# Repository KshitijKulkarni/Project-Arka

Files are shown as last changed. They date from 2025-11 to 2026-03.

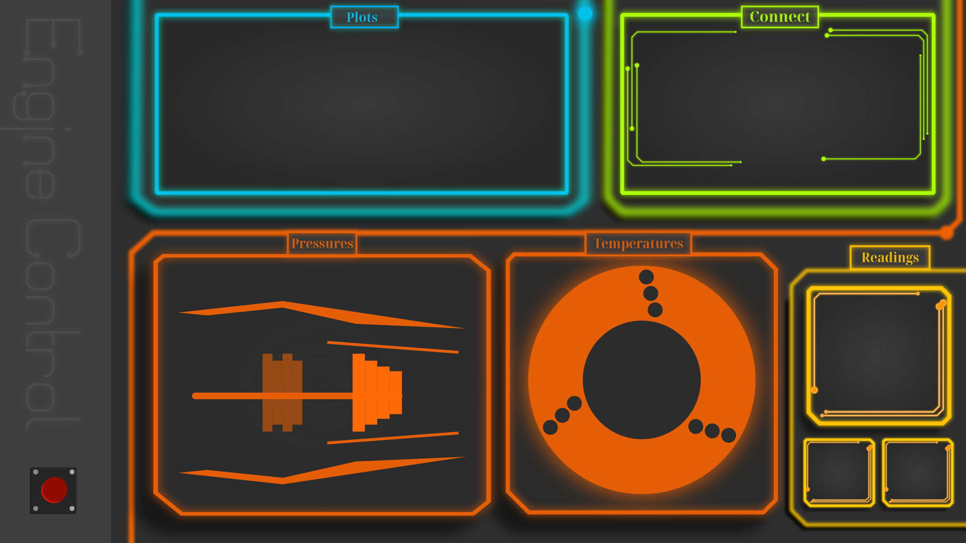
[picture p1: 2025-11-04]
Ground Control Code/Flutter/flutterprojs/assets/BGNew.png

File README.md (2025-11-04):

# Project-Arka
The project code base is split on two folders
1. Microcontroller Code - All code that will be run/tested on microcontrollers (Teensy 4.1, Arduino UNO etc)
2. Ground Control Code - All code that will be run on a system external to the engine (includes code for the GUI)

## Microcontroller Code
The files in this folder are sorted as follows
```
Microcontroller Code
├── moduleTestCodes
└── <microcontrollerBoardname>
    ├── <microcontrollerBoardname>.ino
    └── src
        ├── HelperModule1
        │   ├── HelperModule1.h
        │   └── HelperModule1.cpp
        ├── HelperModule2
        │   ├── HelperModule2.h
        │   └── HelperModule2.cpp
        └── HelperModule3
            ├── HelperModule3.h
            └── HelperModule3.cpp
```

The moduleTestCodes directory contains code for testing individual sensor/motor modules, which are not directly suitable for reuse in the final project.

## Ground Control Code

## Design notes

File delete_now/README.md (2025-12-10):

# delete_now

A new Flutter project.

## Getting Started

This project is a starting point for a Flutter application.

A few resources to get you started if this is your first Flutter project:

- [Lab: Write your first Flutter app](https://docs.flutter.dev/get-started/codelab)
- [Cookbook: Useful Flutter samples](https://docs.flutter.dev/cookbook)

For help getting started with Flutter development, view the
[online documentation](https://docs.flutter.dev/), which offers tutorials,
samples, guidance on mobile development, and a full API reference.

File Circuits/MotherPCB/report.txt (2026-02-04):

Plotted to 'C:\Users\akkia\Downloads\Arka_PCB\Project-Arka\Circuits\MotherPCB\MotherPCB-Front.gbr'.
Plotted to 'C:\Users\akkia\Downloads\Arka_PCB\Project-Arka\Circuits\MotherPCB\MotherPCB-Back.gbr'.
Plotted to 'C:\Users\akkia\Downloads\Arka_PCB\Project-Arka\Circuits\MotherPCB\MotherPCB-F_Paste.gbr'.
Plotted to 'C:\Users\akkia\Downloads\Arka_PCB\Project-Arka\Circuits\MotherPCB\MotherPCB-B_Paste.gbr'.
Plotted to 'C:\Users\akkia\Downloads\Arka_PCB\Project-Arka\Circuits\MotherPCB\MotherPCB-F_Silkscreen.gbr'.
Plotted to 'C:\Users\akkia\Downloads\Arka_PCB\Project-Arka\Circuits\MotherPCB\MotherPCB-B_Silkscreen.gbr'.
Plotted to 'C:\Users\akkia\Downloads\Arka_PCB\Project-Arka\Circuits\MotherPCB\MotherPCB-F_Mask.gbr'.
Plotted to 'C:\Users\akkia\Downloads\Arka_PCB\Project-Arka\Circuits\MotherPCB\MotherPCB-B_Mask.gbr'.
Plotted to 'C:\Users\akkia\Downloads\Arka_PCB\Project-Arka\Circuits\MotherPCB\MotherPCB-Edge_Cuts.gbr'.
Created Gerber job file 'C:\Users\akkia\Downloads\Arka_PCB\Project-Arka\Circuits\MotherPCB\MotherPCB-job.gbrjob'.
Info: Done.
Info: Done.

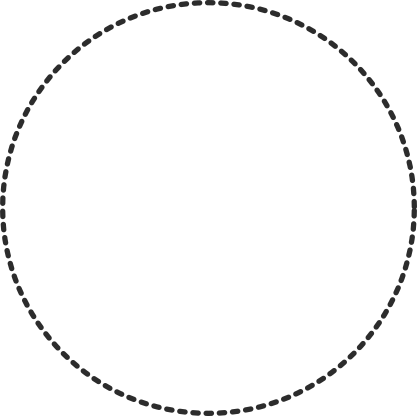
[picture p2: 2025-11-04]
Ground Control Code/Flutter/flutterprojs/assets/L.png

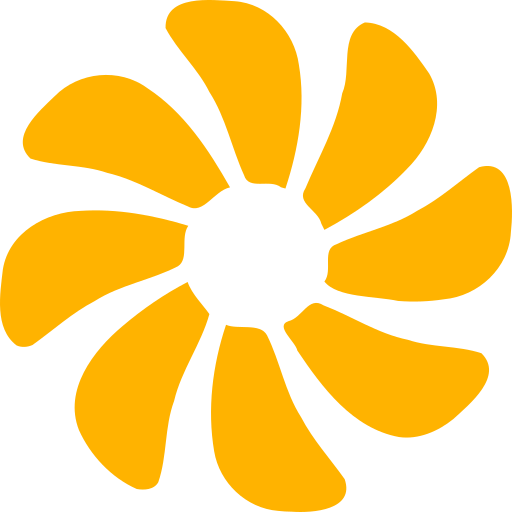
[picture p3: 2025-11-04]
Ground Control Code/Control Panel GUI/QtGUI/UntitledProject/UntitledProjectContent/images/Fan Blades.png

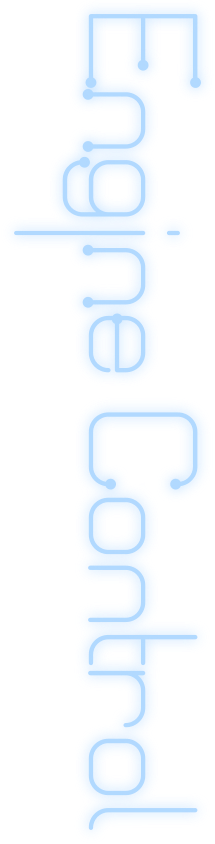
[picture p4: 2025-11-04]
Ground Control Code/Control Panel GUI/QtGUI/UntitledProject/UntitledProjectContent/images/Signboard.png

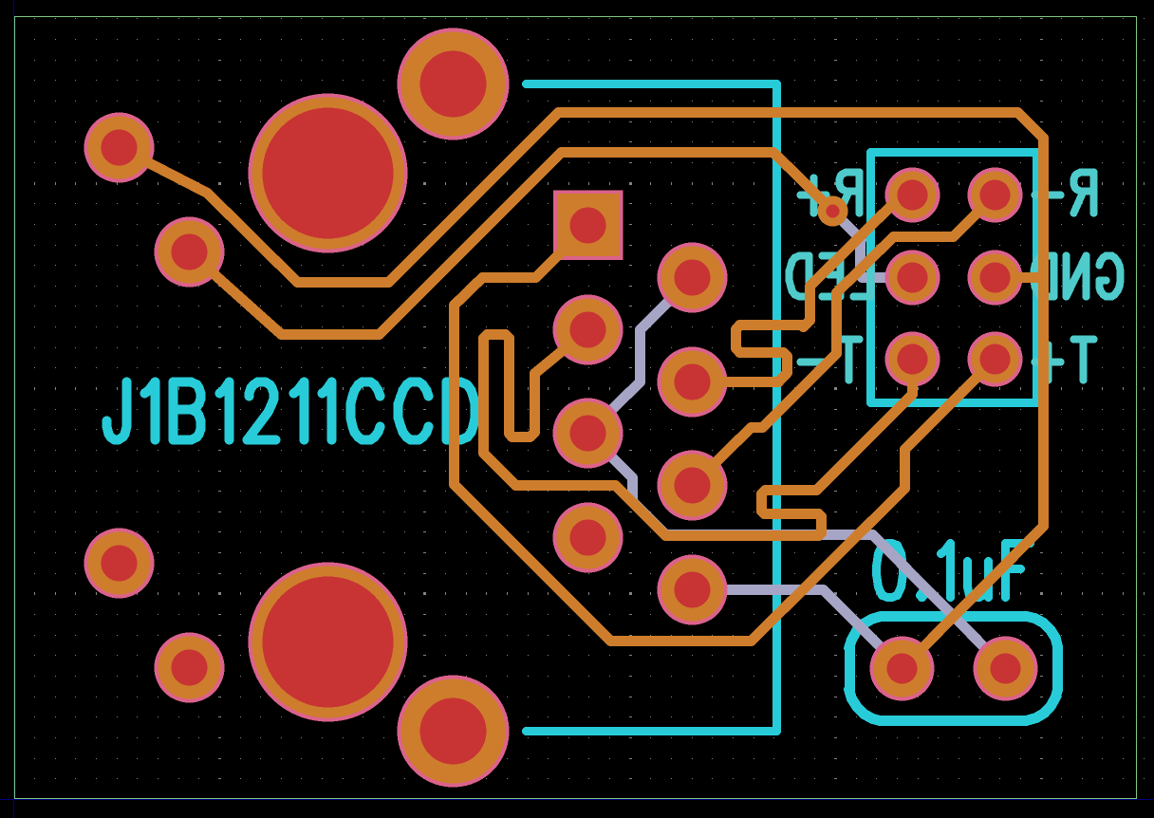
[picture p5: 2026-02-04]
Circuits/EthernetPCB/Screenshot 2026-02-04 032015.png

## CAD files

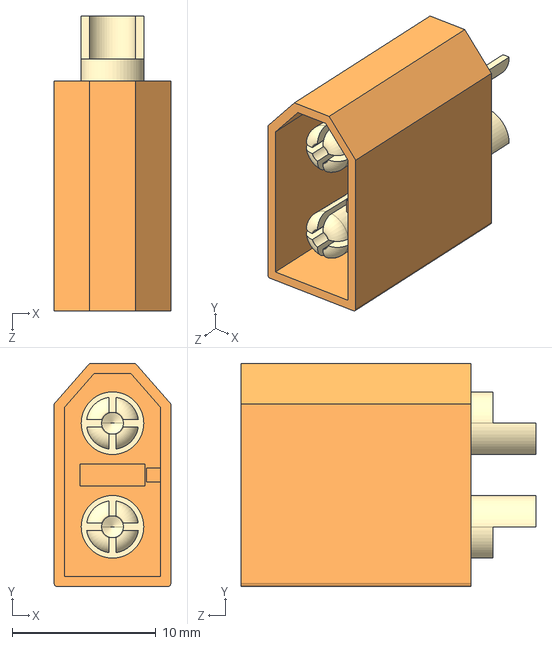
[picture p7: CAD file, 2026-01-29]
Circuits/MotherPCB/Project Libaray/3D Models/XT60-M.step
8.10 x 15.5 x 20.5 mm

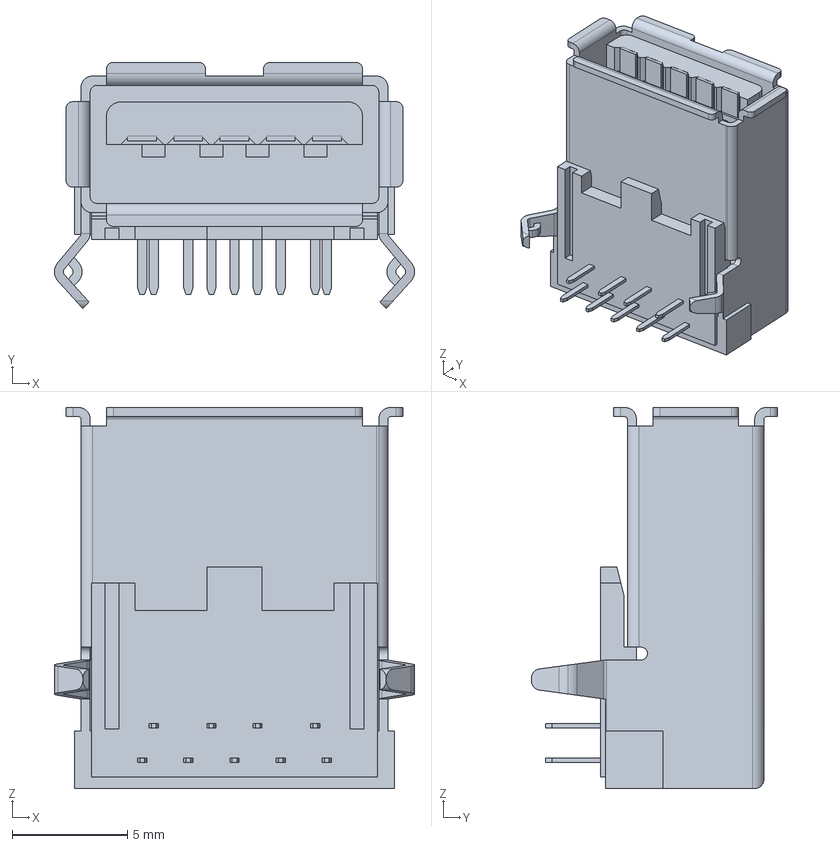
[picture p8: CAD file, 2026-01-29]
Circuits/MotherPCB/Project Libaray/3D Models/usb3_a-usb3_a.stp
15.6 x 10.7 x 16.5 mm

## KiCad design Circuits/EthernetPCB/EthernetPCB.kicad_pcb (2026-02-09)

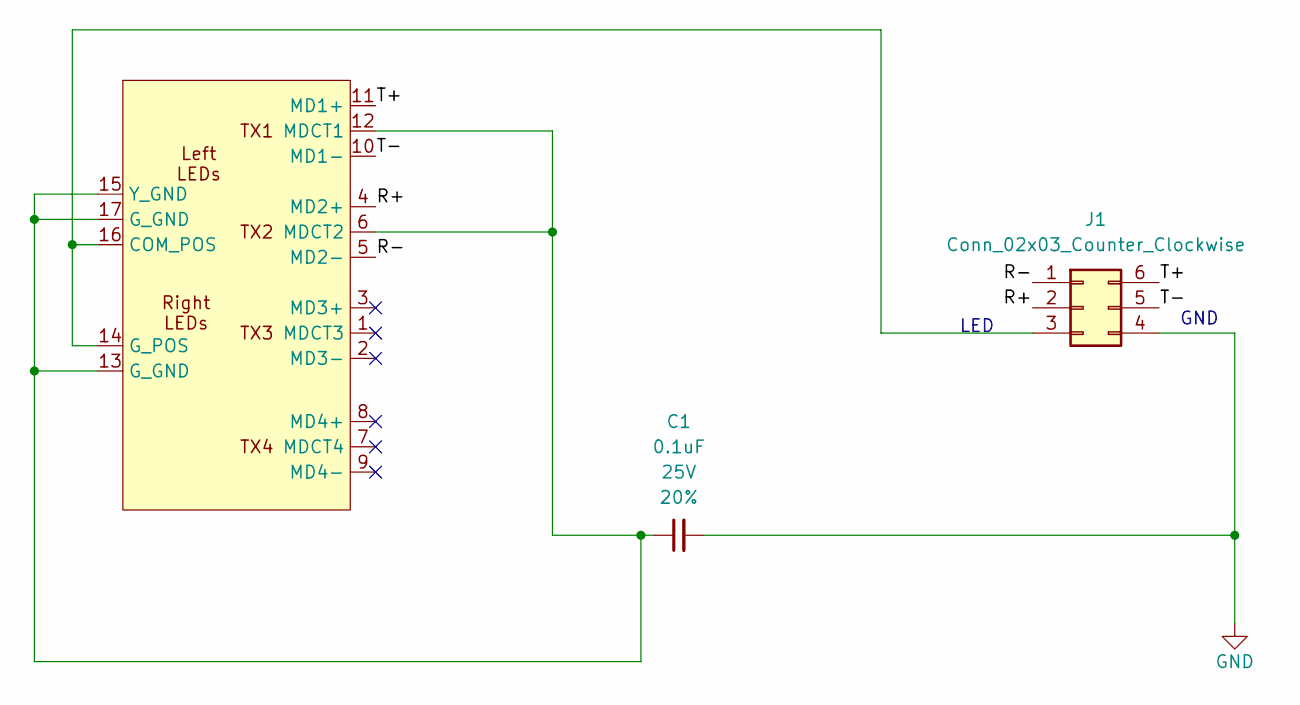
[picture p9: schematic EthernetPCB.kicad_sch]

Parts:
C1: 0.1uF; C_Disc_D3.0mm_W2.0mm_P2.50mm; Voltage 25V; Tolerance 20%
J1: Conn_02x03_Counter_Clockwise; PinHeader_2x03_P2.54mm_Vertical
U1: LINK-PP LPJK7003B97NL

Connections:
/R+: J1.2, U1.4 (MD2+)
/R-: J1.1, U1.5 (MD2-)
/T+: J1.6, U1.11 (MD1+)
/T-: J1.5, U1.10 (MD1-)
GND: C1.2, J1.4
unnamed: J1.3, U1.14 (G_POS), U1.16 (COM_POS)
unnamed: C1.1, U1.6 (MDCT2), U1.12 (MDCT1), U1.13 (G_GND), U1.15 (Y_GND), U1.17 (G_GND)

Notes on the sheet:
LED
GND

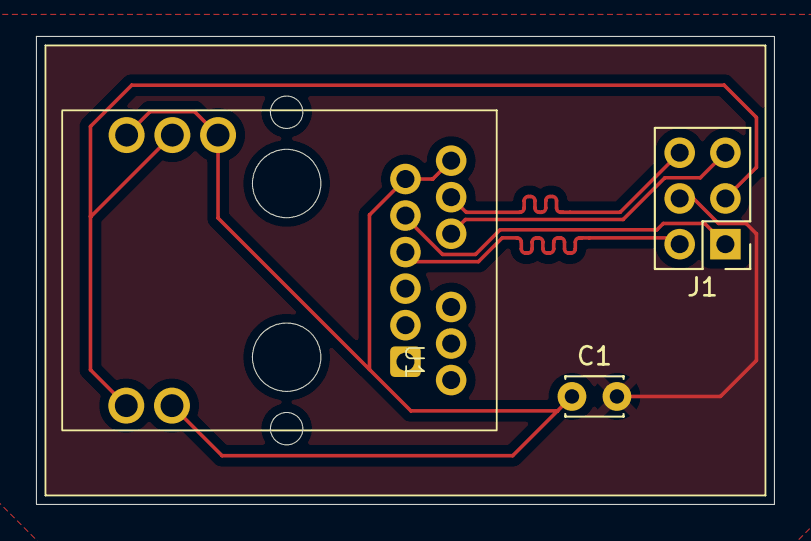
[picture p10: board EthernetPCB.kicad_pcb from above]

Board: 2 copper layers, 41.0 x 26.0 mm, 3 parts (0 on the bottom side), 7 nets.

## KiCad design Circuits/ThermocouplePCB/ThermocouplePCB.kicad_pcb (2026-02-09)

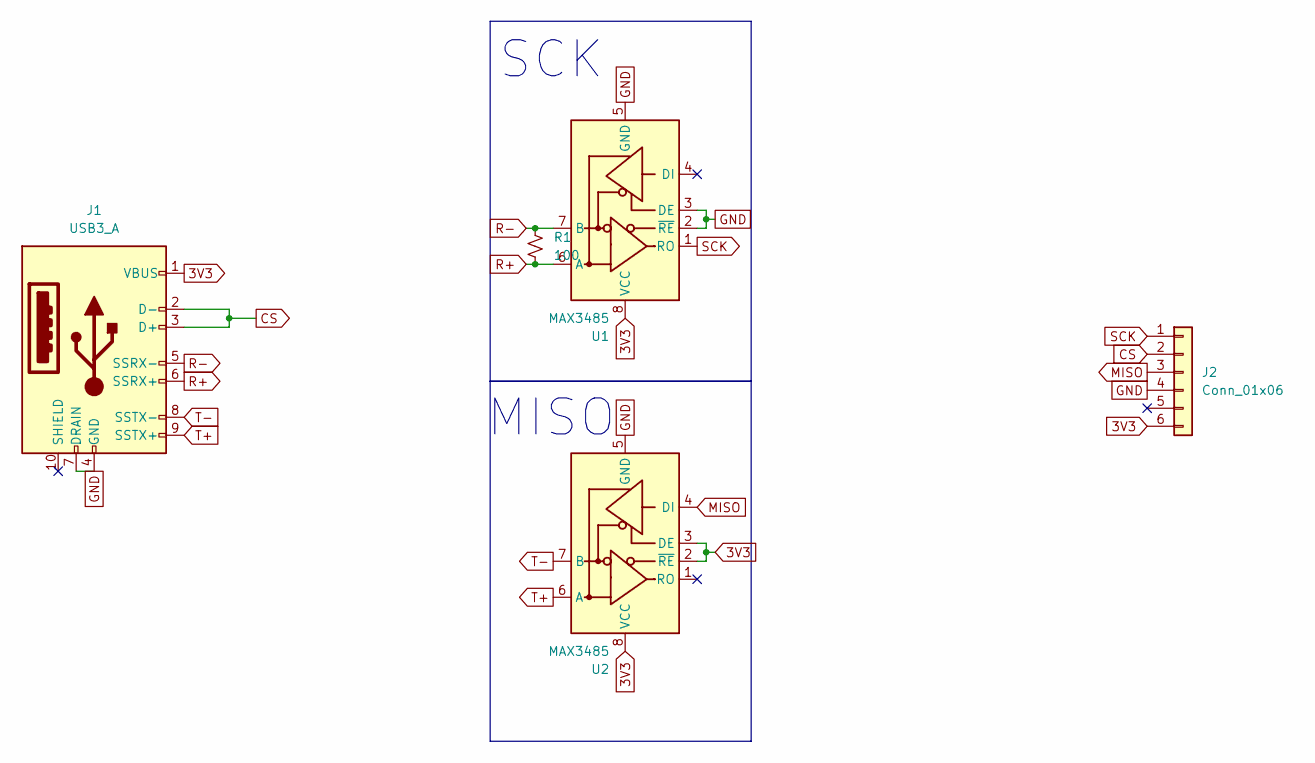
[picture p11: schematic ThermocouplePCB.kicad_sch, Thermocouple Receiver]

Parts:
J1: USB3_A; SAMTEC_USB3-A-S-F-TH
J2: Conn_01x06; PinSocket_1x06_P2.54mm_Vertical
R1: 100; R_Axial_DIN0207_L6.3mm_D2.5mm_P7.62mm_Horizontal
U1, U2: MAX3485; SOIC-8_3.9x4.9mm_P1.27mm

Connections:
3V3: J1.1 (VBUS), J2.6, U1.8 (VCC), U2.2 (~RE), U2.3 (DE), U2.8 (VCC)
CS: J1.2 (D-), J1.3 (D+), J2.2
GND: J1.4 (GND), J1.7 (DRAIN), J2.4, U1.2 (~RE), U1.3 (DE), U1.5 (GND), U2.5 (GND)
MISO: J2.3, U2.4 (DI)
R+: J1.6 (SSRX+), R1.1, U1.6 (A)
R-: J1.5 (SSRX-), R1.2, U1.7 (B)
SCK: J2.1, U1.1 (RO)
T+: J1.9 (SSTX+), U2.6 (A)
T-: J1.8 (SSTX-), U2.7 (B)

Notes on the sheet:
SCK
MISO

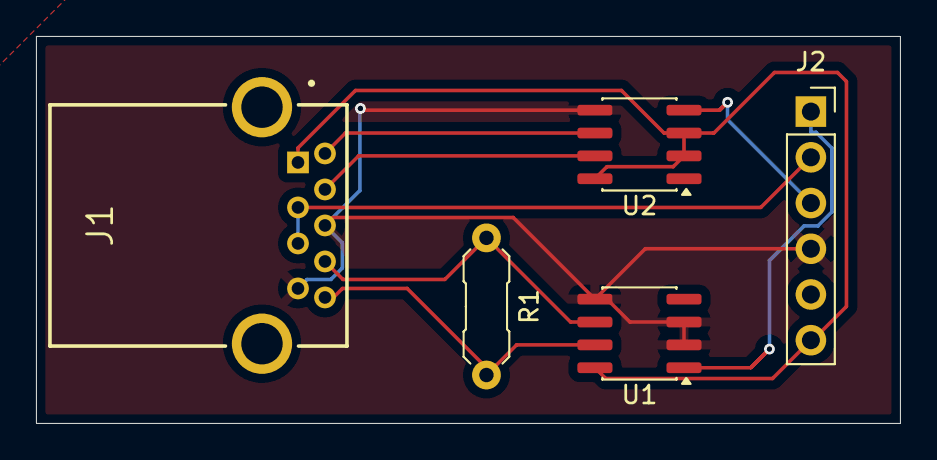
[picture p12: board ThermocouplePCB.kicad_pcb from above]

Board: 2 copper layers, 48.0 x 21.5 mm, 5 parts (0 on the bottom side), 9 nets.

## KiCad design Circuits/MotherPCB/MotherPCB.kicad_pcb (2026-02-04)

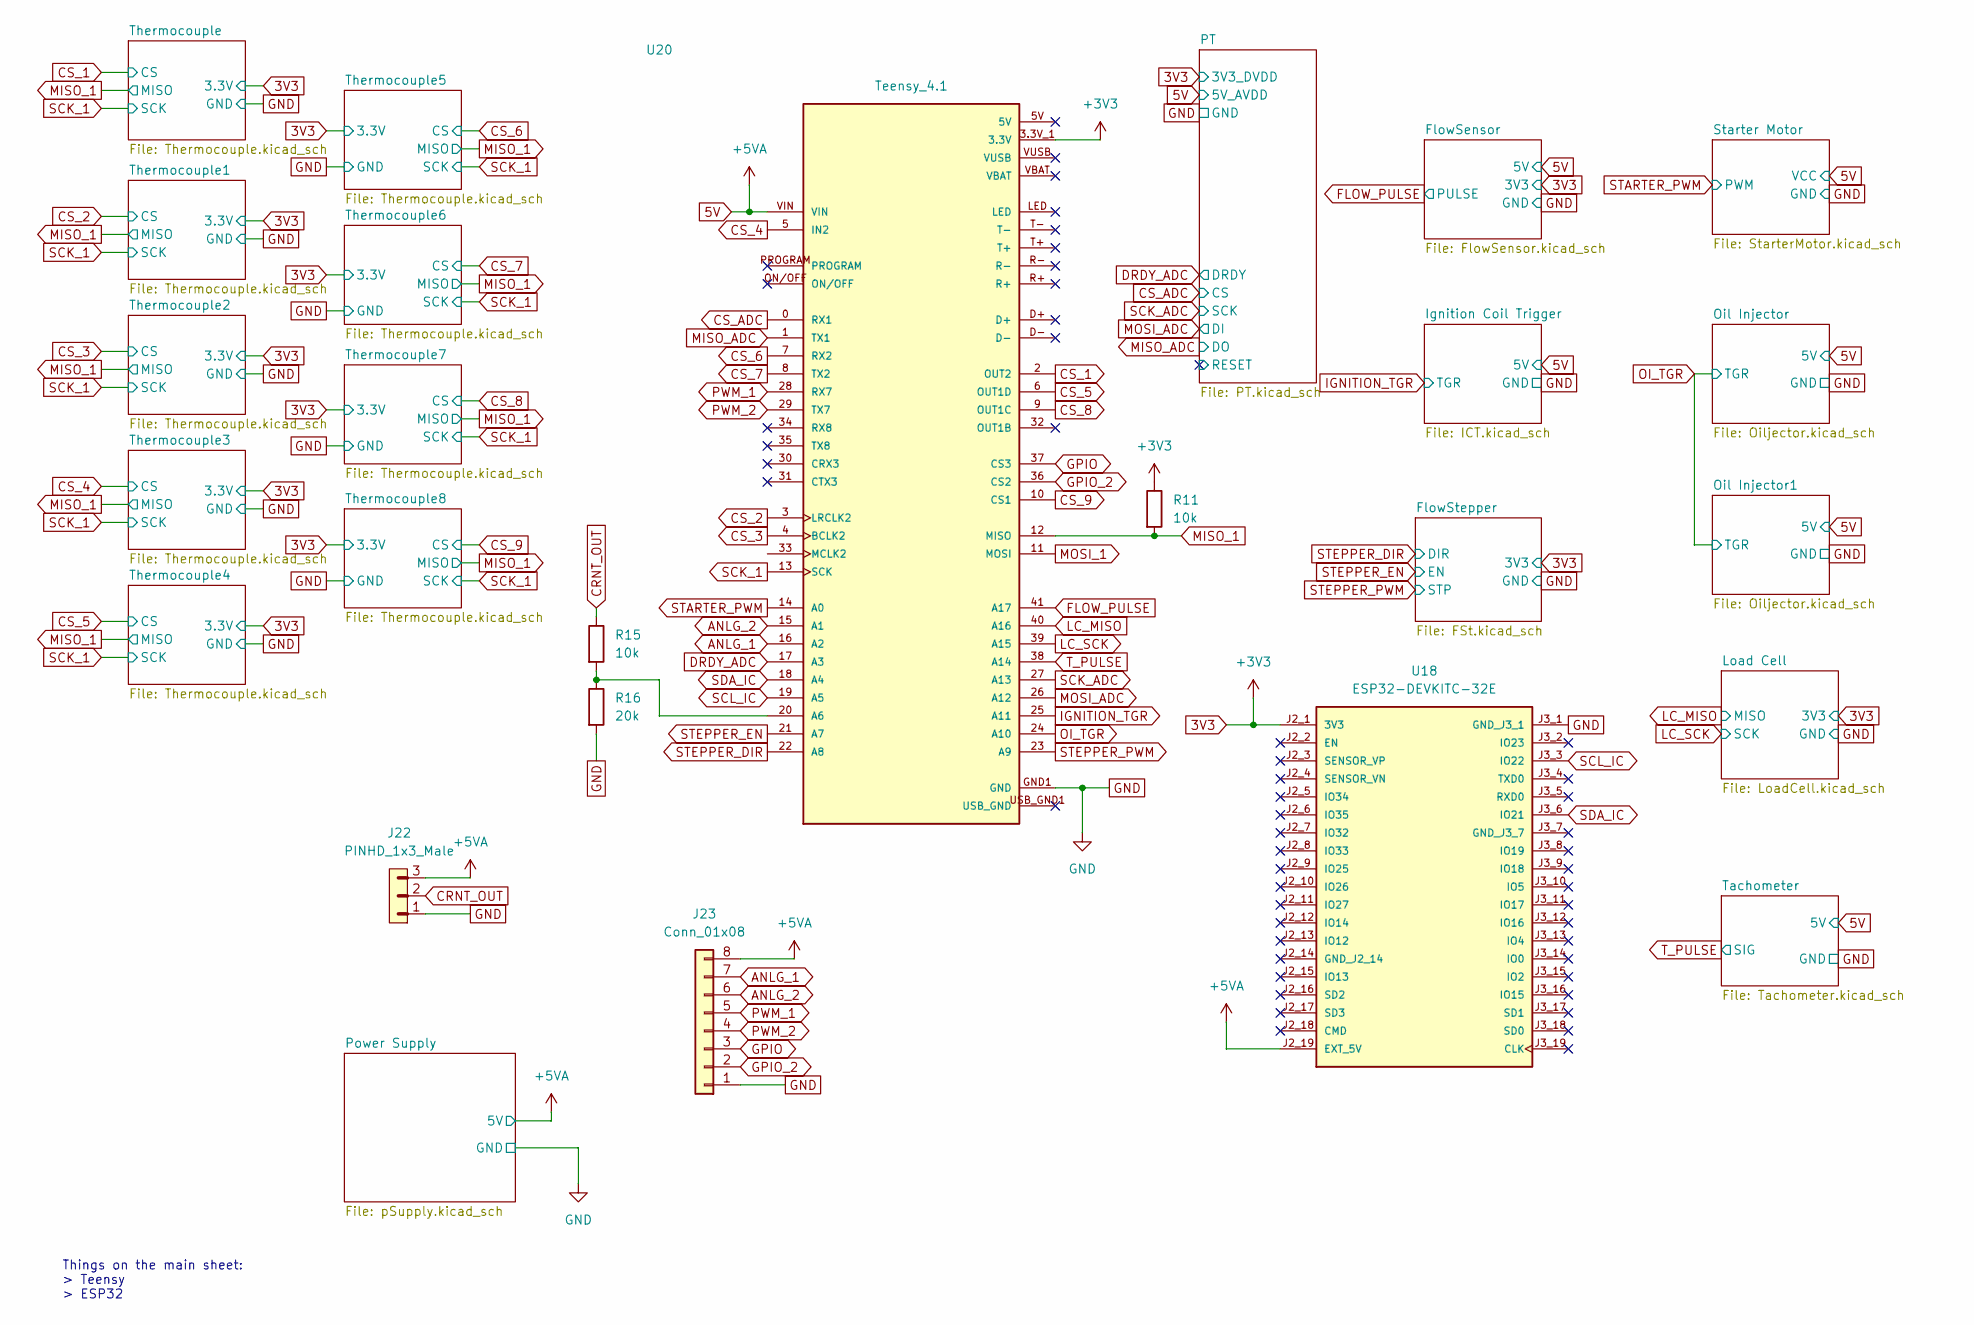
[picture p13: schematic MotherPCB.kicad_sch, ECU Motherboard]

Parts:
J22: PINHD_1x3_Male; PinHeader_1x03_P2.54mm_Vertical
J23: Conn_01x08; PinHeader_1x08_P2.54mm_Vertical
R11, R15: 10k; R_Axial_DIN0207_L6.3mm_D2.5mm_P7.62mm_Horizontal
R16: 20k; R_Axial_DIN0207_L6.3mm_D2.5mm_P7.62mm_Horizontal
U18: ESP32-DEVKITC-32E; MODULE_ESP32-DEVKITC-32E; PARTREV 1.4
U20: Teensy_4.1; PARTREV 4.1

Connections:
3V3: R11.1, U18.J2_1 (3V3), U20.3.3V_1 (3.3V), U20.3.3V_2 (3.3V), U20.3.3V_3 (3.3V); also elsewhere on the board
5V: J22.3, J23.8, U18.J2_19 (EXT_5V), U20.VIN; also elsewhere on the board
ANLG_1: J23.7, U20.16 (A2)
ANLG_2: J23.6, U20.15 (A1)
CRNT_OUT: J22.2, R15.1
CS_1: U20.2 (OUT2); also elsewhere on the board
CS_2: U20.3 (LRCLK2); also elsewhere on the board
CS_3: U20.4 (BCLK2); also elsewhere on the board
CS_4: U20.5 (IN2); also elsewhere on the board
CS_5: U20.6 (OUT1D); also elsewhere on the board
CS_6: U20.7 (RX2); also elsewhere on the board
CS_7: U20.8 (TX2); also elsewhere on the board
CS_8: U20.9 (OUT1C); also elsewhere on the board
CS_9: U20.10 (CS1); also elsewhere on the board
CS_ADC: U20.0 (RX1); also elsewhere on the board
DRDY_ADC: U20.17 (A3); also elsewhere on the board
FLOW_PULSE: U20.41 (A17); also elsewhere on the board
GND: J22.1, J23.1, R16.2, U18.J3_1 (GND_J3_1), U20.GND1 (GND), U20.GND2 (GND), U20.GND3 (GND), U20.GND4 (GND), U20.GND5 (GND); also elsewhere on the board
GPIO: J23.3, U20.37 (CS3)
GPIO_2: J23.2, U20.36 (CS2)
IGNITION_TGR: U20.25 (A11); also elsewhere on the board
LC_MISO: U20.40 (A16); also elsewhere on the board
LC_SCK: U20.39 (A15); also elsewhere on the board
MISO_1: R11.2, U20.12 (MISO); also elsewhere on the board
MISO_ADC: U20.1 (TX1); also elsewhere on the board
MOSI_1: U20.11 (MOSI)
MOSI_ADC: U20.26 (A12); also elsewhere on the board
unnamed: R15.2, R16.1, U20.20 (A6)
OI_TGR: U20.24 (A10); also elsewhere on the board
PWM_1: J23.5, U20.28 (RX7)
PWM_2: J23.4, U20.29 (TX7)
SCK_1: U20.13 (SCK); also elsewhere on the board
SCK_ADC: U20.27 (A13); also elsewhere on the board
SCL_IC: U18.J3_3 (IO22), U20.19 (A5)
SDA_IC: U18.J3_6 (IO21), U20.18 (A4)
STARTER_PWM: U20.14 (A0); also elsewhere on the board
STEPPER_DIR: U20.22 (A8); also elsewhere on the board
STEPPER_EN: U20.21 (A7); also elsewhere on the board
STEPPER_PWM: U20.23 (A9); also elsewhere on the board
T_PULSE: U20.38 (A14); also elsewhere on the board

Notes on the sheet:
Things on the main sheet: > Teensy > ESP32

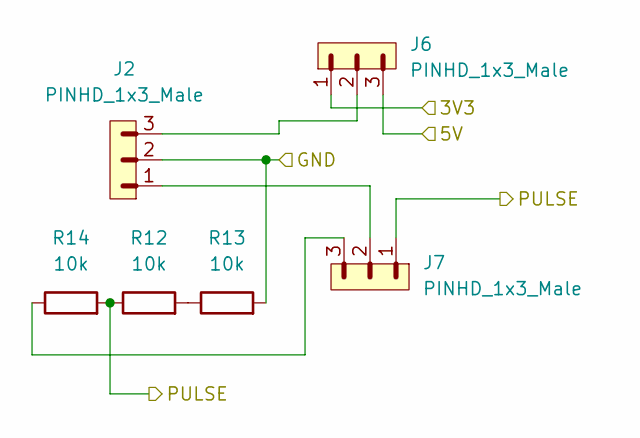
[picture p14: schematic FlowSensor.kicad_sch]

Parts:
J2, J6, J7: PINHD_1x3_Male; PinHeader_1x03_P2.54mm_Vertical
R12, R13, R14: 10k; R_Axial_DIN0207_L6.3mm_D2.5mm_P7.62mm_Horizontal

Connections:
3V3: J6.1; also elsewhere on the board
5V: J6.3; also elsewhere on the board
FLOW_PULSE: J7.1, R12.1, R14.2; also elsewhere on the board
GND: J2.2, R13.2; also elsewhere on the board
unnamed: J2.1, J7.2
unnamed: J2.3, J6.2
unnamed: J7.3, R14.1
unnamed: R12.2, R13.1

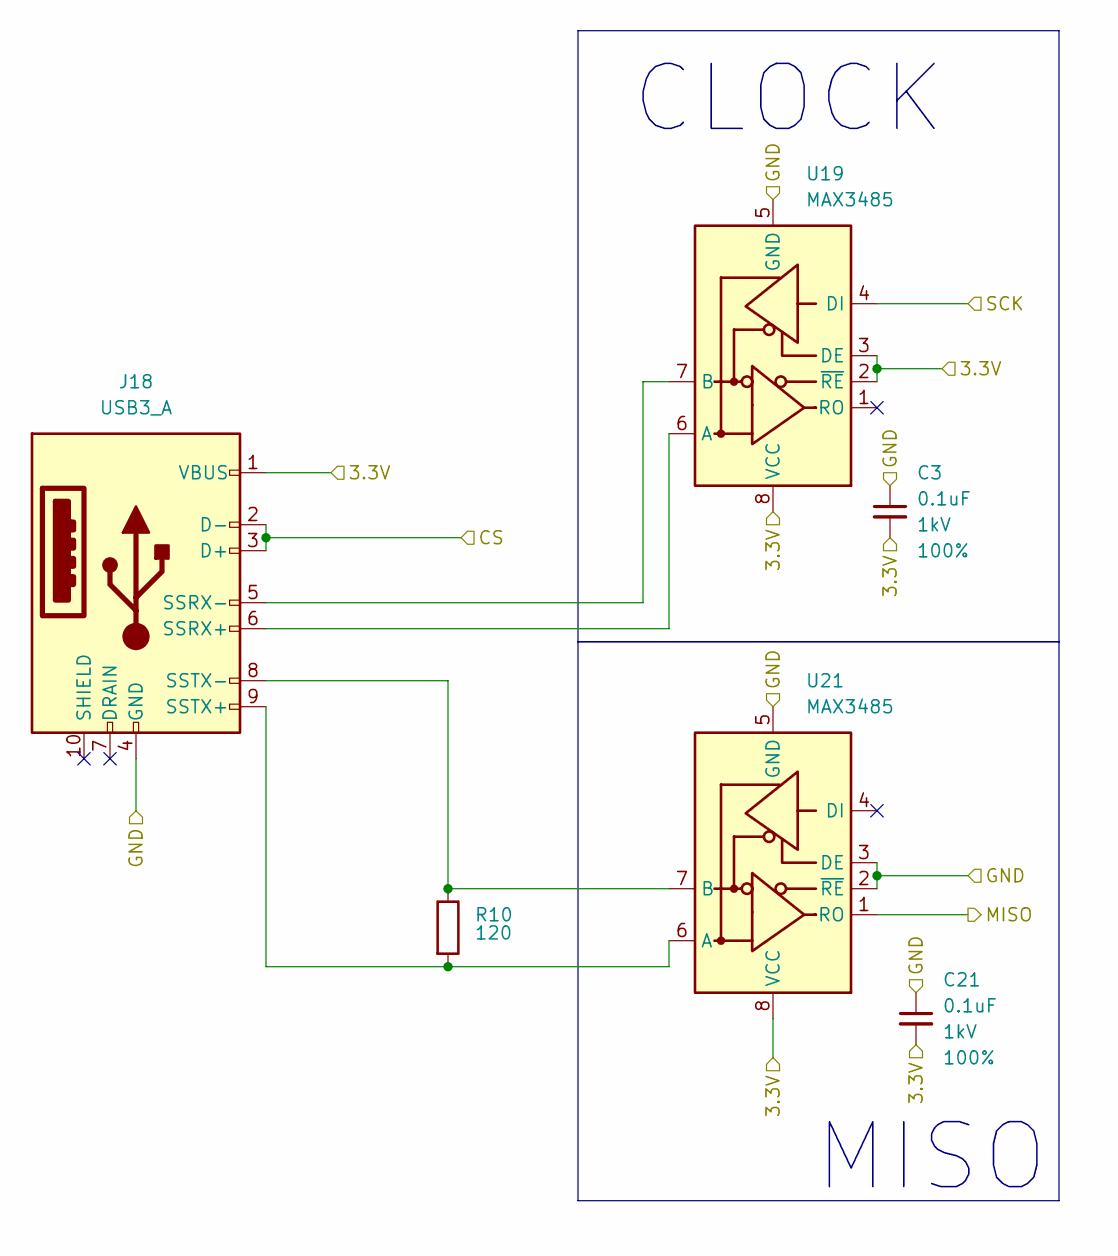
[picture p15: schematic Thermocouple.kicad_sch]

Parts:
C3, C21: 0.1uF; C_Disc_D5.0mm_W2.5mm_P5.00mm; Voltage 1kV; Tolerance 100%
J18: USB3_A; SAMTEC_USB3-A-S-F-TH
R10: 120; R_Axial_DIN0207_L6.3mm_D2.5mm_P7.62mm_Horizontal
U19, U21: MAX3485; SOIC-8_3.9x4.9mm_P1.27mm

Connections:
3V3: C3.2, C21.2, J18.1 (VBUS), U19.2 (~RE), U19.3 (DE), U19.8 (VCC), U21.8 (VCC); also elsewhere on the board
CS_1: J18.2 (D-), J18.3 (D+); also elsewhere on the board
GND: C3.1, C21.1, J18.4 (GND), U19.5 (GND), U21.2 (~RE), U21.3 (DE), U21.5 (GND); also elsewhere on the board
MISO_1: U21.1 (RO); also elsewhere on the board
unnamed: J18.6 (SSRX+), U19.6 (A)
unnamed: J18.5 (SSRX-), U19.7 (B)
unnamed: J18.9 (SSTX+), R10.2, U21.6 (A)
unnamed: J18.8 (SSTX-), R10.1, U21.7 (B)
SCK_1: U19.4 (DI); also elsewhere on the board

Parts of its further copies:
C4, C5, C6, C7, C8, C9, C10, C11, C12, C13, C14, C15, C16, C17, C18, C20: 0.1uF; C_Disc_D5.0mm_W2.5mm_P5.00mm; Voltage 1kV; Tolerance 100%
J1, J9, J10, J11, J12, J13, J14, J15: USB3_A; SAMTEC_USB3-A-S-F-TH
R1, R2, R3, R4, R5, R6, R7, R8: 120; R_Axial_DIN0207_L6.3mm_D2.5mm_P7.62mm_Horizontal
U2, U3, U4, U5, U6, U7, U8, U9, U10, U11, U12, U13, U14, U15, U16, U17: MAX3485; SOIC-8_3.9x4.9mm_P1.27mm

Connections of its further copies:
3V3: C4.2, C5.2, C6.2, C7.2, C8.2, C9.2, C10.2, C11.2, C12.2, C13.2, C14.2, C15.2, C16.2, C17.2, C18.2, C20.2, J1.1 (VBUS), J9.1 (VBUS), J10.1 (VBUS), J11.1 (VBUS), J12.1 (VBUS), J13.1 (VBUS), J14.1 (VBUS), J15.1 (VBUS), U2.2 (~RE), U2.3 (DE), U2.8 (VCC), U3.8 (VCC), U4.2 (~RE), U4.3 (DE), U4.8 (VCC), U5.8 (VCC), U6.2 (~RE), U6.3 (DE), U6.8 (VCC), U7.8 (VCC), U8.2 (~RE), U8.3 (DE), U8.8 (VCC), U9.8 (VCC), U10.2 (~RE), U10.3 (DE), U10.8 (VCC), U11.8 (VCC), U12.2 (~RE), U12.3 (DE), U12.8 (VCC), U13.8 (VCC), U14.2 (~RE), U14.3 (DE), U14.8 (VCC), U15.8 (VCC), U16.2 (~RE), U16.3 (DE), U16.8 (VCC), U17.8 (VCC); also elsewhere on the board
CS_2: J9.2 (D-), J9.3 (D+); also elsewhere on the board
CS_3: J1.2 (D-), J1.3 (D+); also elsewhere on the board
CS_4: J10.2 (D-), J10.3 (D+); also elsewhere on the board
CS_5: J11.2 (D-), J11.3 (D+); also elsewhere on the board
CS_6: J12.2 (D-), J12.3 (D+); also elsewhere on the board
CS_7: J13.2 (D-), J13.3 (D+); also elsewhere on the board
CS_8: J14.2 (D-), J14.3 (D+); also elsewhere on the board
CS_9: J15.2 (D-), J15.3 (D+); also elsewhere on the board
GND: C4.1, C5.1, C6.1, C7.1, C8.1, C9.1, C10.1, C11.1, C12.1, C13.1, C14.1, C15.1, C16.1, C17.1, C18.1, C20.1, J1.4 (GND), J9.4 (GND), J10.4 (GND), J11.4 (GND), J12.4 (GND), J13.4 (GND), J14.4 (GND), J15.4 (GND), U2.5 (GND), U3.2 (~RE), U3.3 (DE), U3.5 (GND), U4.5 (GND), U5.2 (~RE), U5.3 (DE), U5.5 (GND), U6.5 (GND), U7.2 (~RE), U7.3 (DE), U7.5 (GND), U8.5 (GND), U9.2 (~RE), U9.3 (DE), U9.5 (GND), U10.5 (GND), U11.2 (~RE), U11.3 (DE), U11.5 (GND), U12.5 (GND), U13.2 (~RE), U13.3 (DE), U13.5 (GND), U14.5 (GND), U15.2 (~RE), U15.3 (DE), U15.5 (GND), U16.5 (GND), U17.2 (~RE), U17.3 (DE), U17.5 (GND); also elsewhere on the board
MISO_1: U3.1 (RO), U5.1 (RO), U7.1 (RO), U9.1 (RO), U11.1 (RO), U13.1 (RO), U15.1 (RO), U17.1 (RO); also elsewhere on the board
unnamed: J1.6 (SSRX+), U4.6 (A)
unnamed: J1.5 (SSRX-), U4.7 (B)
unnamed: J1.9 (SSTX+), R2.2, U5.6 (A)
unnamed: J1.8 (SSTX-), R2.1, U5.7 (B)
unnamed: J9.6 (SSRX+), U2.6 (A)
unnamed: J9.5 (SSRX-), U2.7 (B)
unnamed: J9.9 (SSTX+), R1.2, U3.6 (A)
unnamed: J9.8 (SSTX-), R1.1, U3.7 (B)
unnamed: J10.6 (SSRX+), U6.6 (A)
unnamed: J10.5 (SSRX-), U6.7 (B)
unnamed: J10.9 (SSTX+), R3.2, U7.6 (A)
unnamed: J10.8 (SSTX-), R3.1, U7.7 (B)
unnamed: J11.6 (SSRX+), U8.6 (A)
unnamed: J11.5 (SSRX-), U8.7 (B)
unnamed: J11.9 (SSTX+), R4.2, U9.6 (A)
unnamed: J11.8 (SSTX-), R4.1, U9.7 (B)
unnamed: J12.6 (SSRX+), U10.6 (A)
unnamed: J12.5 (SSRX-), U10.7 (B)
unnamed: J12.9 (SSTX+), R5.2, U11.6 (A)
unnamed: J12.8 (SSTX-), R5.1, U11.7 (B)
unnamed: J13.6 (SSRX+), U12.6 (A)
unnamed: J13.5 (SSRX-), U12.7 (B)
unnamed: J13.9 (SSTX+), R6.2, U13.6 (A)
unnamed: J13.8 (SSTX-), R6.1, U13.7 (B)
unnamed: J14.6 (SSRX+), U14.6 (A)
unnamed: J14.5 (SSRX-), U14.7 (B)
unnamed: J14.9 (SSTX+), R7.2, U15.6 (A)
unnamed: J14.8 (SSTX-), R7.1, U15.7 (B)
unnamed: J15.6 (SSRX+), U16.6 (A)
unnamed: J15.5 (SSRX-), U16.7 (B)
unnamed: J15.9 (SSTX+), R8.2, U17.6 (A)
unnamed: J15.8 (SSTX-), R8.1, U17.7 (B)
SCK_1: U2.4 (DI), U4.4 (DI), U6.4 (DI), U8.4 (DI), U10.4 (DI), U12.4 (DI), U14.4 (DI), U16.4 (DI); also elsewhere on the board

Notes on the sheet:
CLOCK
MISO

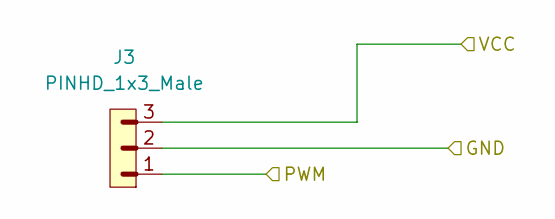
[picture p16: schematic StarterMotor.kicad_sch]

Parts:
J3: PINHD_1x3_Male; PinHeader_1x03_P2.54mm_Vertical

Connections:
5V: J3.3; also elsewhere on the board
GND: J3.2; also elsewhere on the board
STARTER_PWM: J3.1; also elsewhere on the board

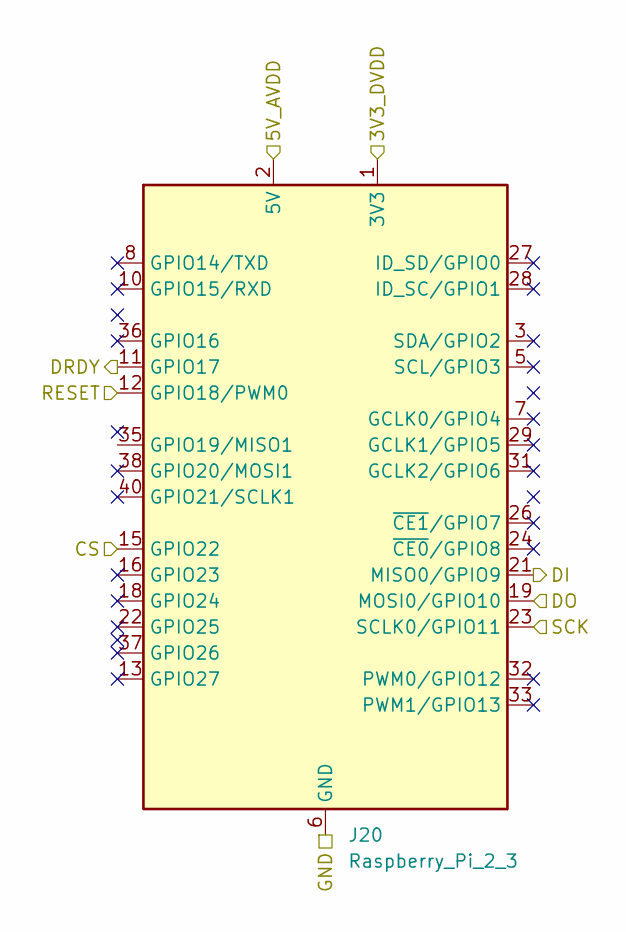
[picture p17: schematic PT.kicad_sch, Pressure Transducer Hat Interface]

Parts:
J20: Raspberry_Pi_2_3; PinHeader_2x20_P2.54mm_Vertical

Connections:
3V3: J20.1 (3V3), J20.17 (3V3); also elsewhere on the board
5V: J20.2 (5V), J20.4 (5V); also elsewhere on the board
/PT/RESET: J20.12 (GPIO18/PWM0)
CS_ADC: J20.15 (GPIO22); also elsewhere on the board
DRDY_ADC: J20.11 (GPIO17); also elsewhere on the board
GND: J20.6 (GND), J20.9 (GND), J20.14 (GND), J20.20 (GND), J20.25 (GND), J20.30 (GND), J20.34 (GND), J20.39 (GND); also elsewhere on the board
MISO_ADC: J20.19 (MOSI0/GPIO10); also elsewhere on the board
MOSI_ADC: J20.21 (MISO0/GPIO9); also elsewhere on the board
SCK_ADC: J20.23 (SCLK0/GPIO11); also elsewhere on the board

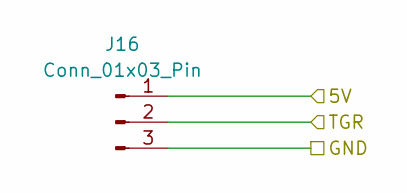
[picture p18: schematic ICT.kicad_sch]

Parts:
J16: Conn_01x03_Pin; PinHeader_1x03_P2.54mm_Vertical

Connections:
5V: J16.1; also elsewhere on the board
GND: J16.3; also elsewhere on the board
IGNITION_TGR: J16.2; also elsewhere on the board

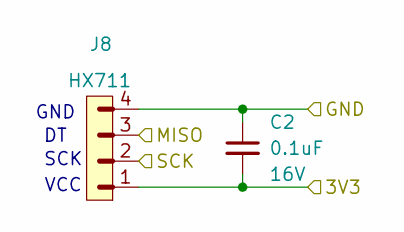
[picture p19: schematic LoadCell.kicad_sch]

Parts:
C2: 0.1uF; C_Disc_D5.0mm_W2.5mm_P5.00mm; Voltage 16V; Tolerance 10%
J8: HX711; PinHeader_1x04_P2.54mm_Vertical

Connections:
3V3: C2.2, J8.1; also elsewhere on the board
GND: C2.1, J8.4; also elsewhere on the board
LC_MISO: J8.3; also elsewhere on the board
LC_SCK: J8.2; also elsewhere on the board

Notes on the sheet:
SCK
GND
VCC

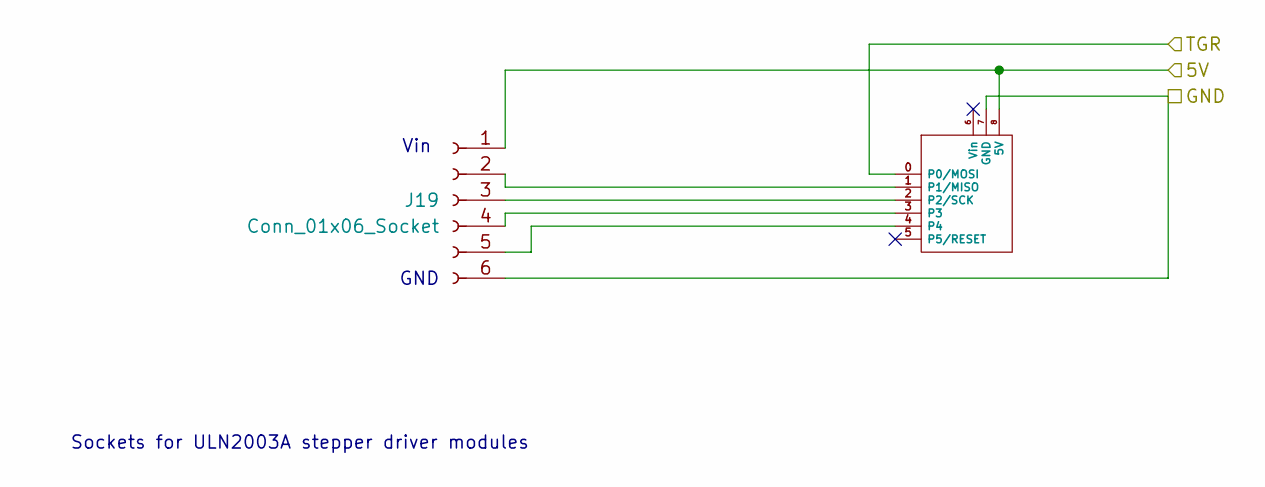
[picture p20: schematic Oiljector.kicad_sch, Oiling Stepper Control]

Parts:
I1: Digispark_ATTiny85_Headers
J19: Conn_01x06_Socket; PinHeader_1x06_P2.54mm_Vertical

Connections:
5V: I1.8 (5V), J19.1; also elsewhere on the board
GND: I1.7 (GND), J19.6; also elsewhere on the board
unnamed: I1.1 (P1/MISO), J19.2
unnamed: I1.2 (P2/SCK), J19.3
unnamed: I1.3, J19.4
unnamed: I1.4, J19.5
OI_TGR: I1.0 (P0/MOSI); also elsewhere on the board

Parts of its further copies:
I2: Digispark_ATTiny85_Headers
J17: Conn_01x06_Socket; PinHeader_1x06_P2.54mm_Vertical

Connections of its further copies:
5V: I2.8 (5V), J17.1; also elsewhere on the board
GND: I2.7 (GND), J17.6; also elsewhere on the board
unnamed: I2.1 (P1/MISO), J17.2
unnamed: I2.2 (P2/SCK), J17.3
unnamed: I2.3, J17.4
unnamed: I2.4, J17.5
OI_TGR: I2.0 (P0/MOSI); also elsewhere on the board

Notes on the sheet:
Sockets for ULN2003A stepper driver modules
GND
Vin

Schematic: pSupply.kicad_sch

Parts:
J21: XT60-M; AMASS_XT60-M; PARTREV V1.2
P1: LM2596 Module

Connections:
5V: P1.1 (VO); also elsewhere on the board
GND: P1.2 (GND); also elsewhere on the board
unnamed: J21.N (NEG), P1.4 (GND)
unnamed: J21.P (POS), P1.3 (VI)

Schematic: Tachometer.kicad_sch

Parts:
J4: Conn_01x03_Pin; PinHeader_1x03_P2.54mm_Vertical
R9, R20, R21: 10k; R_Axial_DIN0207_L6.3mm_D2.5mm_P7.62mm_Horizontal

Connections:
5V: J4.2; also elsewhere on the board
GND: J4.3, R9.2; also elsewhere on the board
unnamed: J4.1, R21.1
unnamed: R9.1, R20.2
T_PULSE: R20.1, R21.2; also elsewhere on the board

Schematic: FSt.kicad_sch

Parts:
J5: PINHD_1x5_Male; PinHeader_1x05_P2.54mm_Vertical

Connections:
3V3: J5.5; also elsewhere on the board
GND: J5.4; also elsewhere on the board
STEPPER_DIR: J5.2; also elsewhere on the board
STEPPER_EN: J5.3; also elsewhere on the board
STEPPER_PWM: J5.1; also elsewhere on the board

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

Board: 2 copper layers, 143.5 x 128.0 mm, 83 parts (0 on the bottom side), 91 nets.

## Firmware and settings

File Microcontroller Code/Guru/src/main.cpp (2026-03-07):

#include <Arduino.h>
#include <SPI.h>
#include "FreeRTOS.h"
#include "DataStructs.h"

#include "EthernetComms.h"

#include "StarterMotor.h"

#include "FuelController.h"

#include "FlowSensor.h"
#include "LoadCell.h"
#include "PressureTransducer.h"
#include "Tachometer.h"
#include "Thermocouple.h"

#define STARTER_MOTOR_PWM_PIN 14

#define FUEL_STEPPER_EN_PIN 21
#define FUEL_STEPPER_DIR_PIN 22
#define FUEL_STEPPER_STP_PIN 23

#define DAQ_TASK_COUNT 5

#define FLOW_SENSOR_PIN 41

#define PRESSURE_TRANSDUCER_DRDY_PIN 42
#define PRESSURE_TRANSDUCER_SCK_PIN 41
#define PRESSURE_TRANSDUCER_CS_PIN 10
#define PRESSURE_TRANSDUCER_MISO_PIN 39
#define PRESSURE_TRANSDUCER_MOSI_PIN 40

#define TACHOMETER_PIN 38

#define STEADY_STATE_TEMP_LIMIT 1100
#define STEADY_STATE_RPM_LIMIT 100000

#define STARTUP_RPM_THRESHOLD 40000
#define STARTUP_FUEL_FLOW_THRESHOLD 6 //g per second

#define SHUTDOWN_FUEL_FLOW_THRESHOLD 2 //g per second

TargetState requestState = {0, 0}; // modified according to ground control requests
TargetState targetState = {0, 0}; // controlled by the control tasks
uint8_t engineState = 0;
/*
  Status Bit Mapping:
    -1: Error State
    0 : Engine Off
    1 : Engine Startup
    2 : Engine Running
    3 : Engine Shutdown
*/

// Time slicing has been turned on for FreeRTOS in FreeRTOSConfig.h

/*
  Only headers have been written for the following:
    1. Load Cell (library used: https://github.com/olkal/HX711_ADC)
*/

/*
  Major To-do List:
    1. Fix ESPComms and add i2c interrupt
    2. Add PID tuning function in FuelController class and call it from main.cpp
    3. Data logging tasks do not need mutexes if they are writing to different variables;
        Change the use of mutexes to improve efficiency
    4. ignotor code must be added
*/

uint16_t completionCount = 0;
uint16_t completionMask = (1 << DAQ_TASK_COUNT) - 1; // all DAQ tasks must complete

/*
  Task 0: Tachometer Data Acquisition
  Task 1: Pressure Transducer Data Acquisition
*/

Gyan dataBuffer;
SemaphoreHandle_t dataBufferMutex;

TaskHandle_t tachometerTaskHandle = NULL; //Unused
TaskHandle_t FuelSensorTaskHandle = NULL;
TaskHandle_t PIDComputeTaskHandle = NULL;
TaskHandle_t FuelStepperControlTaskHandle = NULL;
TaskHandle_t EthernetTaskHandle = NULL;

TaskHandle_t StateMonitorTaskHandle = NULL;
TaskHandle_t StateStartupTaskHandle = NULL;
TaskHandle_t StateRunningTaskHandle = NULL;
TaskHandle_t StateShutdownTaskHandle = NULL;
TaskHandle_t StateEmergencyTaskHandle = NULL;

// Interrupts
void tachometerISR() {
  Tachometer::pulseCount++;
}

void fuelSensorISR() {
  BaseType_t xHigherPriorityTaskWoken = pdFALSE;
  vTaskNotifyGiveFromISR(FuelSensorTaskHandle, 
                        &xHigherPriorityTaskWoken);
  portYIELD_FROM_ISR(xHigherPriorityTaskWoken);
}


// Tasks triggered by ISR
static void vTaskFuelSensor(void *args) {
  static double flowrate = 0.0;
  
  while (1) {
    ulTaskNotifyTake(pdTRUE, portMAX_DELAY);

    FlowSensor::interruptCallback();

    flowrate = FlowSensor::calcFlowrate();
    if (flowrate >= 0) {
      if (xSemaphoreTake(dataBufferMutex, (TickType_t)10) == pdTRUE) {
        FlowSensor::writeFlowrateToBuffer();
        xSemaphoreGive(dataBufferMutex);

        // Notify PID task
        FuelController::notifyNewSensorValue(flowrate);
        xTaskNotifyGive(PIDComputeTaskHandle);
      }
    }
  }
}


// Control Sequence Tasks
static void vTaskStateMonitor(void *args) {
  while (1) {

    // Figure out a way to clean this up
    if (dataBuffer.temperature[0] >= STEADY_STATE_TEMP_LIMIT ||
        dataBuffer.temperature[1] >= STEADY_STATE_TEMP_LIMIT ||
        dataBuffer.temperature[2] >= STEADY_STATE_TEMP_LIMIT ||
        dataBuffer.temperature[3] >= STEADY_STATE_TEMP_LIMIT ||
        dataBuffer.temperature[4] >= STEADY_STATE_TEMP_LIMIT ||
        dataBuffer.temperature[5] >= STEADY_STATE_TEMP_LIMIT ||
        dataBuffer.temperature[6] >= STEADY_STATE_TEMP_LIMIT ||
        dataBuffer.temperature[7] >= STEADY_STATE_TEMP_LIMIT ||
        dataBuffer.temperature[8] >= STEADY_STATE_TEMP_LIMIT || 
        dataBuffer.rpm >= STEADY_STATE_RPM_LIMIT) {
      engineState = -1; // Transition to Emergency
      vTaskResume(StateEmergencyTaskHandle); // Resume Emergency Task
    }

    switch(engineState) {
      case 0:
        // Check for engine startup flag
        if (targetState.state == 1) {
          engineState = 1; // Transition to Startup
          vTaskResume(StateStartupTaskHandle); // Resume Startup Task
        }
        break;

      case 1:
        // Check if startup conditions are met
        if (dataBuffer.rpm >= STARTUP_RPM_THRESHOLD &&
            dataBuffer.currFlow >= STARTUP_FUEL_FLOW_THRESHOLD) {
          engineState = 2; // Transition to Running
          // Startup task must detect the change in state and slow down the starter motor before suspending itself
          vTaskResume(StateRunningTaskHandle); // Resume Running Task
        }
        break;

      case 2:
        if (targetState.state == 3) {
          engineState = 3; // Transition to Shutdown
          // Running task must detect the change in state and cut off fuel flow before suspending itself
          vTaskResume(StateShutdownTaskHandle); // Resume Shutdown Task
        }
        break;

      case 3:
        if (targetState.state == 0) {
          engineState = 0; // Transition to Off
          dataBuffer.status = 0; // Update status in data buffer for telemetry
        }
    }
  }
}

static void vTaskStateStartup(void *args) {
  vTaskSuspend(NULL); // Start in suspended state, will be resumed by State Monitor Task
  StarterMotor::Begin(STARTER_MOTOR_PWM_PIN);
  static int attemptCount = 0;
  static int starterSpeed = 0; // Start at full speed
  static int fuelInflow = 0; // flag for whether fuel has been released
  while (1) {
    dataBuffer.status = 1; // Update status in data buffer for telemetry
    
    if (starterSpeed < 100) { 
      StarterMotor::setSpeed(starterSpeed);
      starterSpeed += 5; // Increase speed by 5% every 100 ms
      vTaskDelay(pdMS_TO_TICKS(1000)); // Increase speed every 100 ms
    }

    /*
      1. The ignitors are turned on after the starter motor reaches full speed.
      2. After a delay to ensure the ignitors are functioning, fuel flow is initiated.
      3. Another delay is given to allow for the fuel to be ignited
      4. if the RPM does not increase, then the fuel flow is stopped, and the system retries the fuel release
    */

    if (starterSpeed == 100 && fuelInflow == 0) {
      // ignitor must be activated
      vTaskDelay(pdMS_TO_TICKS(100)); // Delay to ensure ignitor starts before fuel is fed
      targetState.targetFlow = STARTUP_FUEL_FLOW_THRESHOLD;
      fuelInflow = 1;
      vTaskDelay(pdMS_TO_TICKS(2000)); // Delay to ensure fuel starts flowing before checking startup conditions
    }

    if (fuelInflow == 1 && dataBuffer.rpm < STARTUP_RPM_THRESHOLD) {
      targetState.targetFlow = 0; // Stop fuel flow
      fuelInflow = 0;
      attemptCount++;
      if (attemptCount >= 3) {
        engineState = -1; // Transition to Emergency after 3 failed attempts
        vTaskResume(StateEmergencyTaskHandle); // Resume Emergency Task
      }
    }

    if (dataBuffer.rpm >= STARTUP_RPM_THRESHOLD &&
        dataBuffer.currFlow >= STARTUP_FUEL_FLOW_THRESHOLD) {
      engineState = 2; // Transition to Running
    }

    if (engineState != 1) {
      StarterMotor::stop();
      vTaskSuspend(NULL); // Suspend until next startup command
      attemptCount = 0;
      starterSpeed = 0;
      fuelInflow = 0;
    }
  }
}

static void vTaskStateRunning(void *args) {  
  vTaskSuspend(NULL); // Start in suspended state, will be resumed by State Monitor Task
  while (1) {
    dataBuffer.status = 2; // Update status in data buffer for telemetry

    if (requestState.targetFlow > SHUTDOWN_FUEL_FLOW_THRESHOLD &&
        requestState.state == 2) {
      targetState.targetFlow = requestState.targetFlow; // Update target flow based on ground control requests
      dataBuffer.setFlow = targetState.targetFlow;
    }

    if (requestState.targetFlow < SHUTDOWN_FUEL_FLOW_THRESHOLD ||
        requestState.state == 3) {
      targetState.state = 3; // Transition to Shutdown
    }

    if (engineState != 2) {
      vTaskSuspend(NULL); // Suspend until next running command
    }

    vTaskDelay(pdMS_TO_TICKS(100)); // Loop every 100 ms
  }
}

static void vTaskStateShutdown(void *args) {
  vTaskSuspend(NULL); // Start in suspended state, will be resumed by State Monitor Task
  static int shutdownStep = 5;
  static int starterSpeed = 100;
  static int cooldownSpeed = 30;
  while (1) {
    targetState.targetFlow = 0; // Cut off fuel flow
    dataBuffer.status = 3; // Update status in data buffer for telemetry

    StarterMotor::setSpeed(starterSpeed);
    if (starterSpeed != cooldownSpeed && starterSpeed > 0) {
      starterSpeed -= shutdownStep; // Decrease speed by 5% every 100 ms
      vTaskDelay(pdMS_TO_TICKS(1000)); // Decrease speed every 100 ms
    }
    if (starterSpeed == cooldownSpeed) {
      vTaskDelay(pdMS_TO_TICKS(15000)); // Run starter motor at cooldown speed for 30 seconds to prevent heat soak
    }

    if (starterSpeed == 0) {
      StarterMotor::stop();
      targetState.state = 0; // Transition to Off
      vTaskSuspend(NULL); // Suspend until next startup command
    }
  }
}

static void vTaskStateEmergency(void *args) {
  vTaskSuspend(NULL); // Start in suspended state, will be resumed by State Monitor Task
  while (1) {
    // Emergency handling task
    targetState.targetFlow = 0; // Cut off fuel flow
    dataBuffer.status = -1; // Update status in data buffer for telemetry
    vTaskDelay(pdMS_TO_TICKS(100)); // Check every 100 ms
  }
}

// Sensor Data Acquisition Tasks
static void vTaskTachometer(void *args) {
  while (1) {
    // Tachometer data acquisition
    Tachometer::readRPM();
    
    // Data written to Buffer
    if (xSemaphoreTake(dataBufferMutex, (TickType_t)10) == pdTRUE) {
      Tachometer::writeRPMtoBuffer();
      xSemaphoreGive(dataBufferMutex);
    }
  }
}

static void vTaskPressureTransducer(void *args) {
  while (1) {
    // Pressure Transducer data acquisition
    static bool drdy = false;
    static int sensorIndex = 5;

    while(!drdy) {
      sensorIndex = PressureTransducer::readPressure();
      if (sensorIndex <= 0) {
        // -1 comes only when a full cycle is completed
        drdy = true;
      }
    }
    
    // Data written to Buffer
    if (xSemaphoreTake(dataBufferMutex, (TickType_t)10) == pdTRUE) {
      PressureTransducer::writePressureToBuffer();
      xSemaphoreGive(dataBufferMutex);
    }
  }
}


// PID Task for fuel control
static void vTaskPIDCompute(void *args) {
  while (1) {
    // Wait for notification from sensor tasks
    ulTaskNotifyTake(pdTRUE, portMAX_DELAY);

    // Compute PID
    FuelController::computePID();

    // Notify stepper control task
    xTaskNotifyGive(FuelStepperControlTaskHandle);
  }
}

static void vTaskFuelStepperControl(void *args) {
  while (1) {
    ulTaskNotifyTake(pdTRUE, portMAX_DELAY);
    FuelController::runStepper();
  }
}


// Ethernet Communication Task
static void vTaskEthernet(void *args) {
  static EthComms ethComms(&dataBuffer,
                  (const uint8_t[]){0xDE, 0xAD, 0xBE, 0xEF, 0xFE, 0xED},
                  IPAddress(192, 168, 1, 177),
                  IPAddress(192, 168, 1, 100),
                  8888);
  
  static uint8_t packetSpace = BATCH_SIZE; //defined in EthernetComms.h

  while (1) {
    if ((completionCount & completionMask) == completionMask){
      if (xSemaphoreTake(dataBufferMutex, (TickType_t)10) == pdTRUE) {
        packetSpace = ethComms.appendPacket();
        completionCount = 0;
        xSemaphoreGive(dataBufferMutex);
      }
    }

    if (packetSpace <= 0) {
      ethComms.sendPacket();
      packetSpace = BATCH_SIZE;
    }
  }
}


int main(void) {  
  // Sensor Class Initializations
  Tachometer::Begin(0, &completionCount, &dataBuffer);
  PressureTransducer::Begin(&SPI1, 
                            PRESSURE_TRANSDUCER_CS_PIN,
                            1, 
                            &completionCount, 
                            &dataBuffer);
  FlowSensor::Begin(2, &completionCount, &dataBuffer);

  // Fuel Controller Initialization
  FuelController::Begin(FUEL_STEPPER_EN_PIN, 
                        FUEL_STEPPER_DIR_PIN, 
                        FUEL_STEPPER_STP_PIN);

  dataBufferMutex = xSemaphoreCreateMutex();

  // Data Streaming tasks will start immediately
  xTaskCreate(vTaskTachometer, "TachometerTask", 2048, NULL, 3, NULL);
  xTaskCreate(vTaskPressureTransducer, "PTTask", 2048, NULL, 3, NULL);
  xTaskCreate(vTaskFuelSensor, "FuelSensorTask", 2048, NULL, 4, &FuelSensorTaskHandle);
  
  xTaskCreate(vTaskEthernet, "EthernetTask", 2048, NULL, 5, NULL);

  xTaskCreate(vTaskPIDCompute, "PIDComputeTask", 2048, NULL, 6, &PIDComputeTaskHandle);
  xTaskCreate(vTaskFuelStepperControl, "FuelStepperControlTask", 2048, NULL, 6, &FuelStepperControlTaskHandle);

  // Control Sequence Tasks
  xTaskCreate(vTaskStateMonitor, "StateMonitorTask", 2048, NULL, 8, &StateMonitorTaskHandle);
  xTaskCreate(vTaskStateStartup, "StateStartupTask", 2048, NULL, 7, &StateStartupTaskHandle);
  xTaskCreate(vTaskStateRunning, "StateRunningTask", 2048, NULL, 7, &StateRunningTaskHandle);
  xTaskCreate(vTaskStateShutdown, "StateShutdownTask", 2048, NULL, 7, &StateShutdownTaskHandle);
  xTaskCreate(vTaskStateEmergency, "StateEmergencyTask", 2048, NULL, 7, &StateEmergencyTaskHandle);

  // Attaching all interrupts
  attachInterrupt(digitalPinToInterrupt(TACHOMETER_PIN), tachometerISR, arduino::RISING);
  attachInterrupt(digitalPinToInterrupt(FLOW_SENSOR_PIN), fuelSensorISR, arduino::RISING);

  vTaskStartScheduler();

  return 0;  
}

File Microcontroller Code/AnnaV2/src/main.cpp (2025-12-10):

#include <Arduino.h>
#include <WiFi.h>
#include "DataStructs.h"
#include "RemoteComms.h"
#include "LocalComms.h"

Gyan recvData;
ExtGyan sendData;
Directive directiveData;
unsigned long int lastSendTime = 0;
const uint8_t thambiMac[6] = {0xD4, 0x8A, 0xFC, 0xCE, 0xF3, 0x80};

void setup() {
  // put your setup code here, to run once:
  LocalComms::begin(115200);
  RemoteComms::begin(thambiMac);
  
  directiveData.id = 0xAA; // Example directive ID
  directiveData.value = 150; // Example directive value
}

void loop() {
  // put your main code here, to run repeatedly:
  
  // if (RemoteComms::dataAvailable) {
    RemoteComms::getData(&recvData);
    sendData.status = 1; // Example status
    sendData.rpm = recvData.rpm;
    sendData.thrust = recvData.thrust;
    sendData.currFlow = recvData.flow;
    sendData.setFlow = 150; // Example set flow
    for (int i = 0; i < 5; i++) {
      sendData.pressure[i] = recvData.pressure[i];
    }
    for (int i = 0; i < 9; i++) {
      sendData.temperature[i] = recvData.temperature[i];
    }
    // LocalComms::debugData(&sendData);
  // }
  

  if (Serial.available()) {
    if (Serial.read() == 0x61) {
      LocalComms::sendData(&sendData);
    }
  }
  
  if (millis() - lastSendTime >= 1000) {
    lastSendTime = millis();
    RemoteComms::sendData(&directiveData);
  }
}

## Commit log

2025-10-30 Add descriptions for Python and Arduino files
2025-11-04 Restructured Codebase
    [data_run1.csv, data_run1_test.csv, data_run2.csv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]
2025-12-03 Cleaning up after the move to Ground Control Code
    I rebuilt the UI to ensure nothing was broken. This regenerated some cache files and deleted others. Now it's development ready in the new directory
2025-12-08 Added I2C receive code on Thambi
    [data.csv, no_load_data_2.csv, no_load_data_3.csv]
2025-12-08 Added I2C comms on Guru
2026-01-25 KiCad push 1
    [try1.kicad_pcb, try1.kicad_sch]
2026-01-25 The PCB work is now underway!
    [FSt.kicad_sch, FlowSensor.kicad_sch, ICT.kicad_sch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]
2026-01-25 Done for the night
    Finished up thermocouple differential communication and every other module apart from PTs and Oil Injector.
    Good night.
    oh wait
    It's 4:00 am.
    Good morning
    [FSt.kicad_sch, FlowSensor.kicad_sch, ICT.kicad_sch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]
2026-01-26 cleaned up the lib folder of microcontroller code
    [PT.kicad_sch]
2026-01-26 Added footprint for ATTiny85 module, added schematic for oil injector circuit
    [MotherPCB.kicad_sch, Oiljector.kicad_sch, PT.kicad_sch]
2026-01-26 Added Teensy and some labels to the schematic
    [MotherPCB.kicad_sch, Oiljector.kicad_sch, Thermocouple.kicad_sch]
2026-01-28 Schematic Finished
    [ICT.kicad_sch, MotherPCB.kicad_sch, Oiljector.kicad_sch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]
2026-01-28 Fixed some broken footprints
    [ICT.kicad_sch, MotherPCB.kicad_sch, Oiljector.kicad_sch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]
2026-01-29 pcb completed with a clean DRC
    first one it is let us pray it works
    [FSt.kicad_sch, LoadCell.kicad_sch, MotherPCB.kicad_pcb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]
2026-01-29 PCB v2 um
    [FlowSensor.kicad_sch, MotherPCB.kicad_pcb, MotherPCB.kicad_sch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]
2026-02-04 This commit comprises of multiple changes 1. Final MotherPCB (Redesigned by Akshay, only pushed to GitHub by me) 2. PCB for interfacing with the Ethernet MagJack 3. Code for Pressure Transducer data 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
    [EthernetPCB.kicad_pcb, EthernetPCB.kicad_sch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]
2026-02-06 Thermocouple Satellite PCB Added
    [ThermocouplePCB.kicad_pcb, ThermocouplePCB.kicad_sch]
2026-02-09 Final output in thermocouple and ethernet pcb
    Verified. Ground plane added. All systems normal.
    [EthernetPCB.kicad_pcb, EthernetPCB.kicad_sch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]
2026-02-11 Added some headers and Flow Sensor code
2026-02-15 Added code for the fuel sensor, and headers for fuel controller
2026-02-17 Added code for fuel sensor classand fuel controller class (only PID implementation included), stepper motor control pending
2026-03-05 Added Stepper motor control
2026-03-05 Added Starter Motor module, listed control sequence tasks (tasks yet to be populated)
